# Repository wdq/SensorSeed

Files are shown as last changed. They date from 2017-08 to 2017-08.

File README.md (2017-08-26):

# SensorSeed

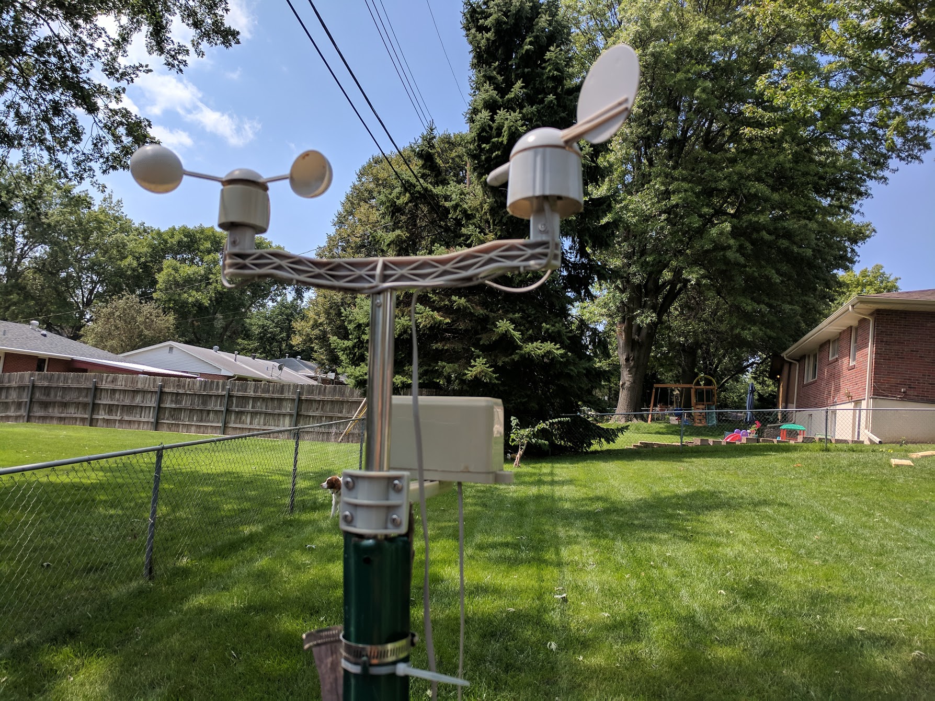
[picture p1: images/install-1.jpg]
Weather station wind and rain sensors


This is everything relating to my weather station project, including C# website code, AVR code for the hardware, PCB layouts, and schematics.

There is an outdoor component to the station that collects temperature, humidity, pressure, wind speed, wind direction, and rain every two and a half minutes, I might bump this up to every minute in the future. Data is pushed over the air using a 100mW 900MHz radio to a Particle Photon inside my house. The Photon is connected to WiFi and uploads the data to the website. 

You can view the data collected from the weather station on [my website](https://sensorseed.quade.co/HomeOutsideWeatherStation/Home), and on the [Weather Underground website](https://www.wunderground.com/personal-weather-station/dashboard?ID=KNELINCO88)

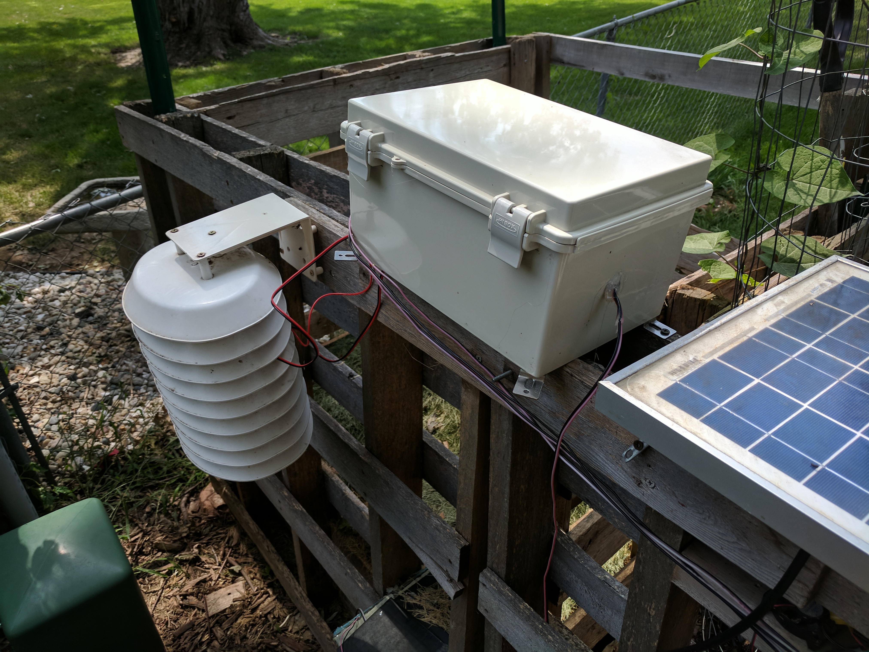
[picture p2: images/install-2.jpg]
Weather station hardware


Parts list: 

| Item | Price | Description |
|---|---|---|
| Outdoor PCB | $15 | The PCB for the outside part of the weather station. I got them made at Elecrow and the price shipped was about $15. |
| Indoor PCB | $15 | The PCB for the indoor part of the weather station. I got them made at Elecrow and the price shipped was about $15. |
| ATmega328p | $2 | Main microcontroller for the outside station. PDIP package. |
| 2x ATtiny44/88 | $4 | I2C slaves that keep track of wind speed and rain outside. PDIP package. |
| 2x Adafruit RFM69HCW | $20 | Radios to handle communication between indoor and outdoor device. I use the 900MHz version with the nine pin breakout. |
| Particle Photon | $20 | The microcontroller for the indoor station. |
| 2x 900MHz antennas | $10 | For the radios. I used right angle SMA ones that Adafruit sells. |
| 2x SMA jacks | $5 | Edge mount SMA jacks for 1.6mm PCBs for the radios. Adafruit sells these. |
| 6x 220 ohm resistors | $0.60 | Through hole package. These are for LEDs, so you can use different sizes based on how bright you want the LEDs to be.  |
| 6x LEDs | $1 | Through hole 5mm LEDs. Any color. |
| 2x 20pF capacitors | $0.20 | Through hole package, ceramic. May be different depending on the crystal oscillator you pick. |
| 6x 0.1uF capacitors | $0.60 | Through hole package, ceramic. For the AVR decoupling. |
| 8MHz crystal | $0.30 | An 8MHz quartz crystal oscillator. You can use other frequencies if you want. |
| 2x 1k ohm resistors | $0.20 | For voltage divider. Through hole. |
| 3x 2k ohm resistors | $0.30 | For voltage divider. Through hole. |
| 10k ohm resistor | $0.10 | For the wind vane. Through hole. |
| 4.7k ohm resistor | $0.10 | Pullup resistor for the radio. Through hole. |
| 2x 10uF capacitors | $0.20 | Bypass capacitors, through hole, one per board, electrolytic. |
| 6x jumpers | $1.00 | Jumpers to turn on/off the LEDs for debugging |
| Pin headers | $1 | Used throughout both boards |
| Pin header sockets | $1 | Used throughout both boards |
| 3x 28 pin DIP sockets | $1 | Used to make the AVR chips removable. |
|  Sparkfun weather meters | $77 | There are lots of distributors. I got mine on Amazon. Has the rain gauge, anemometer, and wind vane. |
| Weatherproof box | $30 | A box to hold the outside station. |
| Solar radiation shield | $40 | Very important for accurate temperature and humidity readings. |
| 35W solar panel | $40 | A panel to charge the battery, bigger is generally better. |
| 12V 18Ah lead acid battery | $40 | To run the outside station. Lead acid charges at lower temperatures than lithium ion. Bigger is generally better. |
| Lead acid solar charge controller | $20 | To charge the battery. |
| Adafruit SHT31-D | $14 | Temperature/humidity sensor. |
| DHT22 | $4 | Temperature/humidity sensor. |
| BMP180 | $4 | Pressure/Temperature/Altitude sensor. |
| Silica Gel packets | $10 | To help keep the outdoor station dry inside the box |
| | | |
| Total: | $378  | 

I recommend buying extras for many of the cheaper electronic parts. That way you can have a replacement board if something goes wrong, and generally buying in bulk is cheaper anyways.

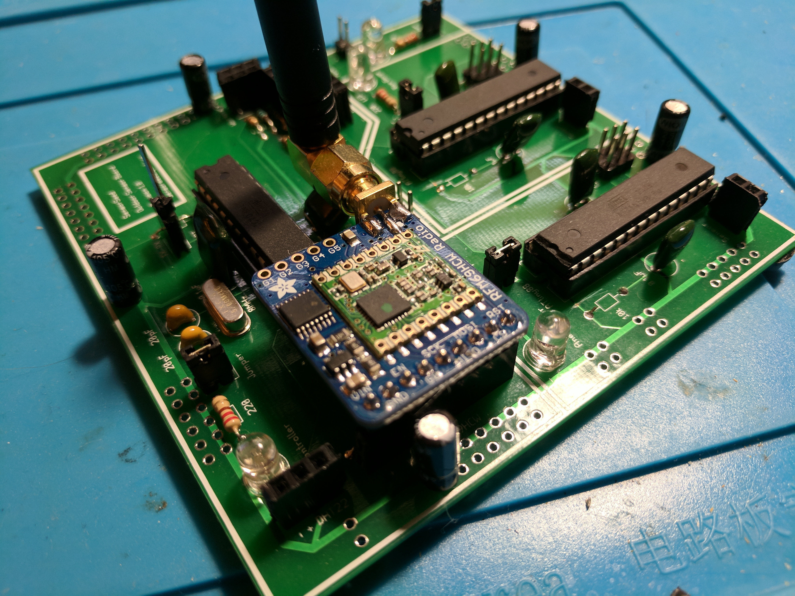
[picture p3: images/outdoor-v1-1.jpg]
Outdoor board

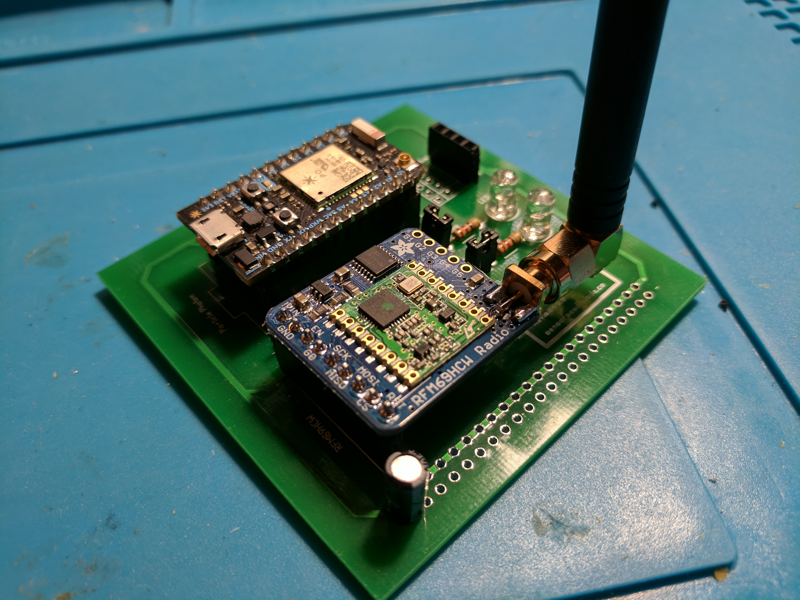
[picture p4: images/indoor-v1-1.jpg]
Indoor board


You can find more images of this station [here](https://github.com/wdq/SensorSeed/tree/master/images).

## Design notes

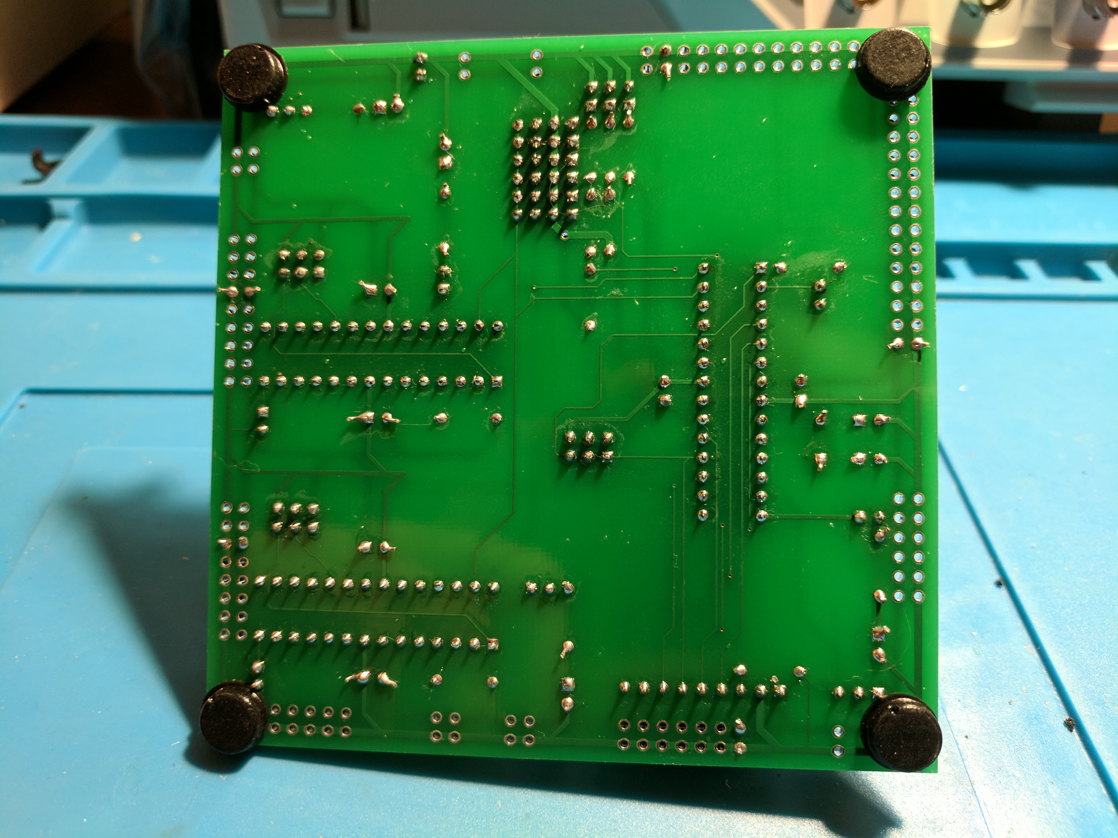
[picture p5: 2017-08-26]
images/outdoor-v1-3.jpg

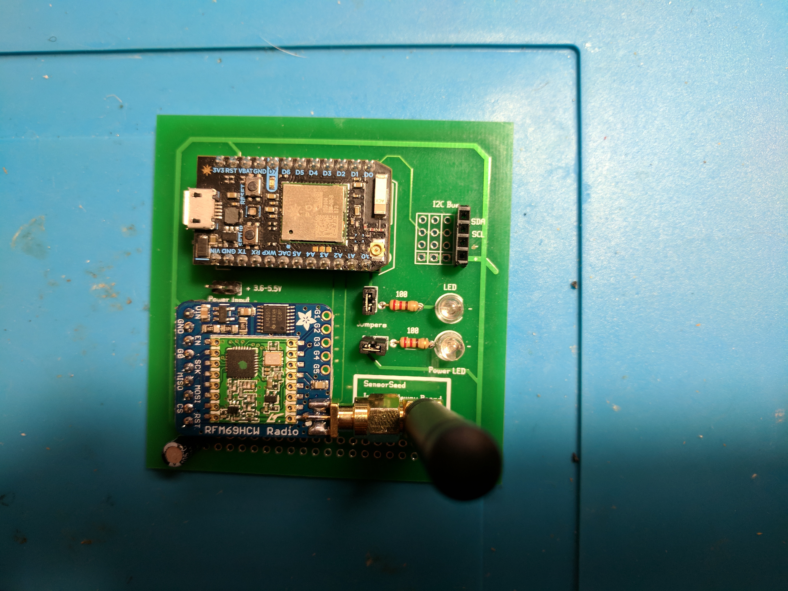
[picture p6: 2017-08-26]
images/indoor-v1-2.jpg

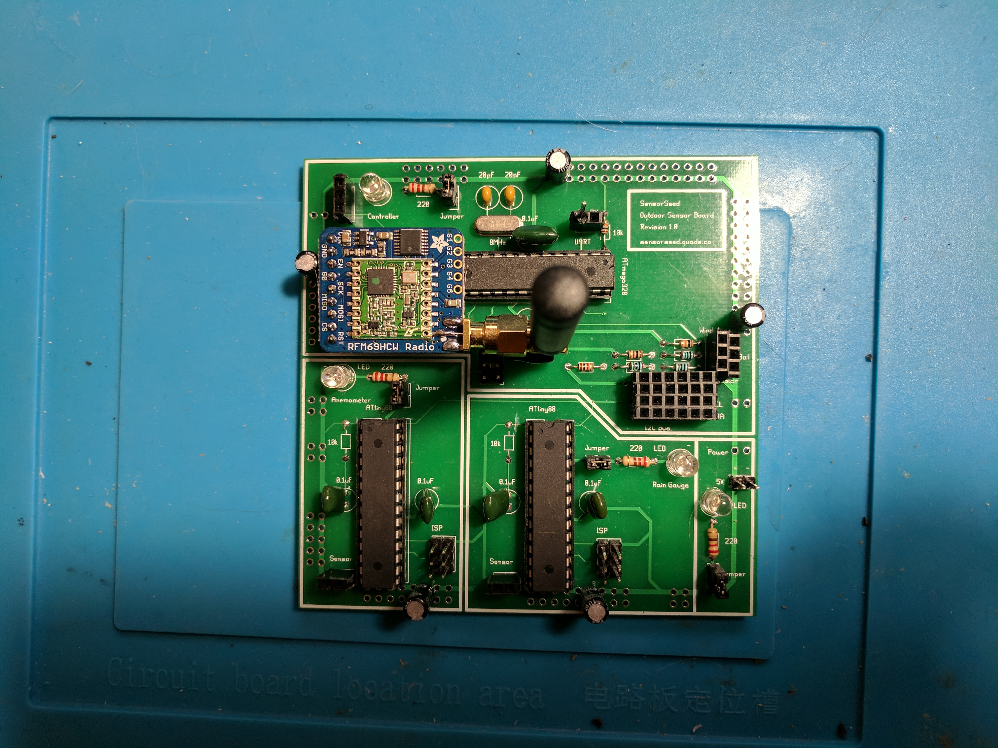
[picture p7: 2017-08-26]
images/outdoor-v1-2.jpg

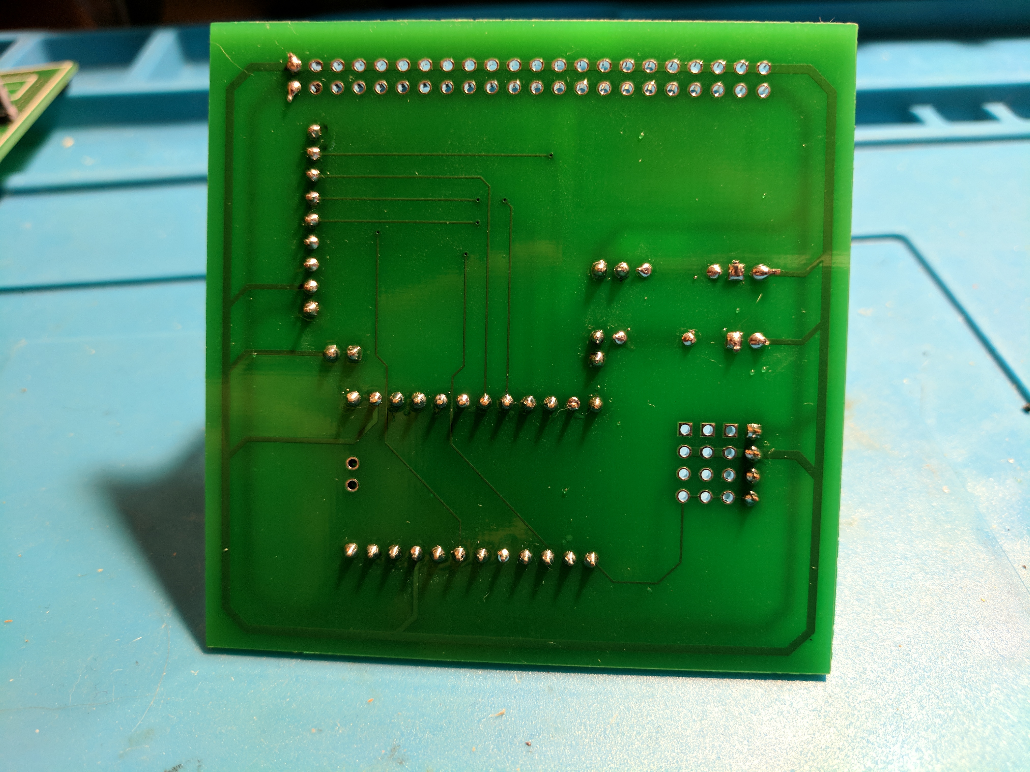
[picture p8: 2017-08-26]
images/indoor-v1-3.jpg

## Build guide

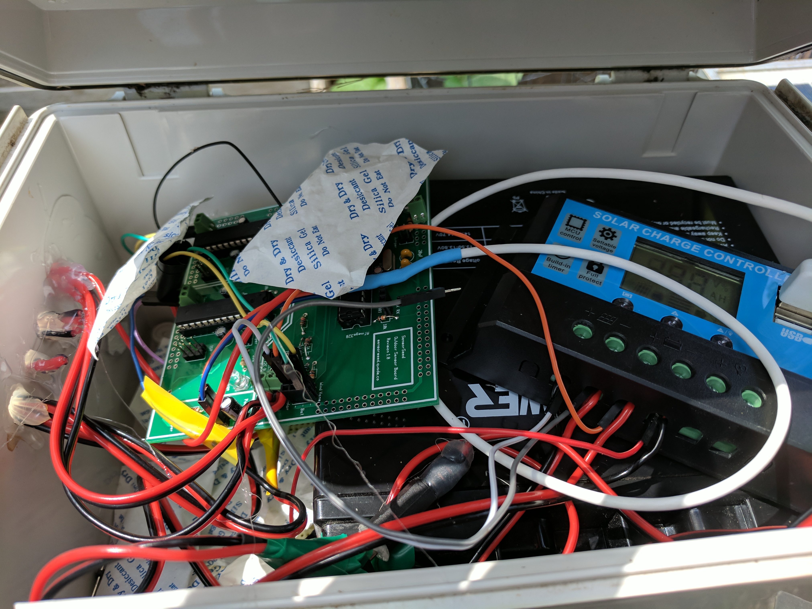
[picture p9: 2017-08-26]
images/install-3.jpg

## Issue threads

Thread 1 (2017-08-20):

Wire.requestFrom() should not be followed by Wire.endTransmission() and no delay is needed after a Wire.requestFrom().

Koepel, 2017-08-20:
In the file "SensorSeed/hardware/avr/outside/outside.ino", the Wire.requestFrom() is followed by a Wire.endTransmission() three times. You can remove those Wire.endTransmission(), since it is should only be used when writing data.

In the function getRain() the Wire.requestFrom() is followed by a `delay(50);`. You can remove that delay, since there is no need to wait after a Wire.requestFrom().

wdq, 2017-08-20:
Thanks for pointing this out, I've updated the code.

Closed 2017-08-20.

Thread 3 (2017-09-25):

Air quality/pollution sensors

wdq, 2017-09-25:
I'd like to add air quality/pollution sensors to the board since they are part of the wunderground API.

Probably won't get around to this until I'm out of school at the end of this year, or in the summer of 2018.

Ideally the sensors would go into the same solar radiation shield that the temperature/humidity/pressure sensors are in, and also use I2C. I'd be designing a new board that goes into there.

Possible fields:

AqNO - [ NO (nitric oxide) ppb ]
AqNO2T - (nitrogen dioxide), true measure ppb
AqNO2 - NO2 computed, NOx-NO ppb
AqNO2Y - NO2 computed, NOy-NO ppb
AqNOX - NOx (nitrogen oxides) - ppb
AqNOY - NOy (total reactive nitrogen) - ppb
AqNO3 -NO3 ion (nitrate, not adjusted for ammonium ion) UG/M3
AqSO4 -SO4 ion (sulfate, not adjusted for ammonium ion) UG/M3
AqSO2 -(sulfur dioxide), conventional ppb
AqSO2T -trace levels ppb
AqCO -CO (carbon monoxide), conventional ppm
AqCOT -CO trace levels ppb
AqEC -EC (elemental carbon) – PM2.5 UG/M3
AqOC -OC (organic carbon, not adjusted for oxygen and hydrogen) – PM2.5 UG/M3
AqBC -BC (black carbon at 880 nm) UG/M3
AqUV-AETH  -UV-AETH (second channel of Aethalometer at 370 nm) UG/M3
AqPM2.5 - PM2.5 mass - UG/M3
AqPM10 - PM10 mass - PM10 mass
AqOZONE - Ozone - ppb

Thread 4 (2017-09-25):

Solar type sensors

wdq, 2017-09-25:
Another part of the wunderground API is solar data.

I tried to do this in the past, but the weather got to the sensors. They need to be in a good glass enclosure where they can see the sky.

Ideally they would use I2C.

I probably won't get around to this until I am off of school at the end of this year, or the summer of 2018.

Data fields:

solarradiation - [W/m^2]
UV - [index]

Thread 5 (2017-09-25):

Add soil type sensors

wdq, 2017-09-25:
Another type of data that the wunderground API supports are for soil sensors.

This is something I have been working on at work, so I might incorporate part of that design into this. That would be a capacitive moisture sensor that has an I2C interface.

Do a single depth at a minimum, but consider doing multiple depths.

I probably won't be getting around to this until the summer of 2018 when I am off of school.

Data fields:

soiltempf - [F soil temperature]
 * for sensors 2,3,4 use soiltemp2f, soiltemp3f, and soiltemp4f
soilmoisture - [%]
* for sensors 2,3,4 use soilmoisture2, soilmoisture3, and soilmoisture4

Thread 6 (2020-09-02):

PCB fabrication

zjobra, 2020-09-02:
Hi!
I've uploaded SensorSeed boards to pcbhubs for easy manufacturing order
https://pcbhubs.com/newpcb/15990737105f4fedae3fdff
https://pcbhubs.com/newpcb/15990737865f4fedfa4907c

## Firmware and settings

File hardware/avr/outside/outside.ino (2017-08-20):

// outside
// This code is for an ATmega328p I2C master to collect data from a bunch of sensors.

#include <Wire.h>
#include <RFM69.h>
#include <SPI.h>
#include <Adafruit_SHT31.h>
#include <Adafruit_Sensor.h>
#include <Adafruit_BMP085_U.h>
#include <DHT.h>
#include <DHT_U.h>
#include <stdlib.h>

#define NETWORKID                               81
#define NODEID                                  2
#define RECEIVER                                1
#define FREQUENCY                               RF69_915MHZ
#define ENCRYPTKEY                              "wquadeEncryptKey"
#define IS_RFM69HCW                             true
#define TRANSMIT_INTERVAL                       90000 // in milliseconds, this is set to 1.5 minutes
#define TIME_BETWEEN_PACKETS                    15000 // 15 seconds

// I2C slaves
#define ANEMOMETER_I2C_ADDRESS                  0x06
#define RAINGAUGE_I2C_ADDRESS                   0x07
#define WIND_FACTOR                             2.4
// IO pins
#define LED_PIN                                 14
#define VANE_PIN                                A1
#define VANE_EN_PIN                             A0
#define SOLAR_PIN                               A3
#define BATTERY_PIN                             A2
#define SERIAL_BAUD                             9600                             
// DHT22
#define DHTPIN                                  7
#define DHTTYPE                                 DHT22
// RFM69HCW
#define RFM69_CS                                4
#define RFM69_IRQ                               3
#define RFM69_IRQN                              1
#define RFM69_RST                               2


int16_t packetnum = 0;
unsigned long previousTransmitMillis = millis();
unsigned long previousPacketSentMillis = millis();
unsigned long previousWindSpeedRetrieveMillis = millis();
bool transmitting = false;

int state = 0;
char radiopacket0[61];
char radiopacket1[61];
char radiopacket2[61];
char radiopacket3[61];
char radiopacket4[61];

RFM69 radio = RFM69(RFM69_CS, RFM69_IRQ, IS_RFM69HCW, RFM69_IRQN);
Adafruit_SHT31 sht31 = Adafruit_SHT31();
Adafruit_BMP085_Unified bmp180 = Adafruit_BMP085_Unified(10085);
DHT_Unified dht(DHTPIN, DHTTYPE);

bool sht31Connected = false;
bool bmp180Connected = false;

void enableRadio() {
  pinMode(RFM69_RST, OUTPUT);
  digitalWrite(RFM69_RST, HIGH);
  delay(100);
  digitalWrite(RFM69_RST, LOW);
  delay(100);
  radio.initialize(FREQUENCY,NODEID,NETWORKID);
  if (IS_RFM69HCW) {
    radio.setHighPower();
  }
  radio.setPowerLevel(31);
  radio.encrypt(ENCRYPTKEY);
  Serial.println(F("Radio enabled"));
}

void setupSensors() {
  // Reset rain gauge and anemometer.
  Serial.print("Resetting rain gauge and anemometer...");
  Wire.beginTransmission(RAINGAUGE_I2C_ADDRESS);
  Wire.write(1);
  Wire.endTransmission();
  Wire.beginTransmission(ANEMOMETER_I2C_ADDRESS);
  Wire.write(1);
  Wire.endTransmission();
  previousWindSpeedRetrieveMillis = millis();
  Serial.println(F("SHT31 begin "));
  sht31Connected = sht31.begin(0x44);
  if(!sht31Connected) {
    Serial.println(F("FAILED"));
  }
  Serial.println(F("BMP180 begin "));
  bmp180Connected = bmp180.begin();
  if(!bmp180Connected) {
    Serial.println(F("FAILED"));
  }
  dht.begin(); // library doesn't return a status on begin
  pinMode(VANE_PIN, INPUT);
  pinMode(VANE_EN_PIN, OUTPUT);
  digitalWrite(VANE_EN_PIN, LOW);
  pinMode(BATTERY_PIN, INPUT);
  pinMode(SOLAR_PIN, INPUT);
  Serial.println(F("Sensors setup"));
}

void setup() {
  Serial.begin(SERIAL_BAUD);
  Serial.println(F("Starting station..."));
  enableRadio();
  setupSensors();

  Serial.println(F("Sending test packet"));
  String packet0 = String();
  String packet0Data = String("Hello world");
  packet0 += String("0:");
  packet0 += packet0Data;
  memset(radiopacket0, 0, sizeof(radiopacket0));
  packet0.toCharArray(radiopacket0, 61);
  Serial.print(F("Sending: ")); Serial.println(radiopacket0);
  radio.send(RECEIVER, radiopacket0, strlen(radiopacket0)); //target node Id, message as string or byte array, message length
  Serial.println(F("OK"));
  radio.receiveDone(); //put radio in RX mode
  Serial.flush(); //make sure all serial data is clocked out before sleeping the MCU  
  Serial.println(F("Finished setup"));
}

bool waitingBetweenPackets = false;
void loop() {
  unsigned long currentMillis = millis();
  if((currentMillis - previousTransmitMillis > TRANSMIT_INTERVAL) && !transmitting) {
    state = 1; // create packets
    Serial.println(F("Creating packets"));
  } else if((currentMillis - previousPacketSentMillis > TIME_BETWEEN_PACKETS) && transmitting) {
    state++;
    waitingBetweenPackets = false;
    Serial.println(F("Incrementing state"));    
  }
  
  if(state == 1) { // create packets
      Serial.println(F("Creating packets"));
      String packet1 = String();
      String packet2 = String();
      String packet3 = String();
      String packet4 = String();

      String temperatureSHT31 = String();
      String humiditySHT32 = String();
      if(sht31Connected) {
        temperatureSHT31 = String(getTemperatureSHT31());
        humiditySHT32 = String(getHumiditySHT31());
      } else {
        temperatureSHT31 = String("0.00");
        humiditySHT32 = String("0.00");
      }
      String pressureBMP180 = String();
      String altitudeBMP180 = String();
      String temperatureBMP180 = String();
      if(bmp180Connected) {
        pressureBMP180 = String(getPressureBMP180());
        altitudeBMP180 = String(getAltitudeBMP180());
        temperatureBMP180 = String(getTemperatureBMP180());
      } else {
        pressureBMP180 = String("0.00");
        altitudeBMP180 = String("0.00");
        temperatureBMP180 = String("0.00");        
      }
      
      String windSpeed = String(getWind());
      String gustSpeed = String(getGust());
      
      String rain = String(getRain());
      String battery = String(getBattery());
      Serial.print(F("Battery string: "));
      Serial.print(battery);
      Serial.print(F(", battery float: "));
      Serial.println(getBattery());
      String solar = String(getSolar());
      
      String windDirection = String(getDirection());
      
      String temperatureDHT22 = String(getTemperatureDHT22());
      String humidityDHT22 = String(getHumidityDHT22());

      packet1 += String("1:");
      packet1 += temperatureSHT31;
      packet1 += String(",");
      packet1 += humiditySHT32;
      packet1 += String(",");  
      packet1 += pressureBMP180;
      packet1 += String(",");
      packet1 += altitudeBMP180;
    
      packet2 += String("2:");  
      packet2 += windSpeed;
      packet2 += String(",");
      packet2 += gustSpeed;
    
      packet3 += String("3:");
      packet3 += rain;
      packet3 += String(",");
      packet3 += battery;
      packet3 += String(",");
      packet3 += solar;
    
      packet4 += String("4:");
      packet4 += windDirection;
      packet4 += String(",");
      packet4 += temperatureBMP180;
      packet4 += String(",");
      packet4 += temperatureDHT22;
      packet4 += String(",");
      packet4 += humidityDHT22;

      memset(radiopacket1, 0, sizeof(radiopacket1));
      memset(radiopacket2, 0, sizeof(radiopacket2));
      memset(radiopacket3, 0, sizeof(radiopacket3));
      memset(radiopacket4, 0, sizeof(radiopacket4));
      packet1.toCharArray(radiopacket1, 61);
      packet2.toCharArray(radiopacket2, 61);
      packet3.toCharArray(radiopacket3, 61);
      packet4.toCharArray(radiopacket4, 61);

      Serial.println(F("All packets are ready"));
      Serial.println(radiopacket1);
      Serial.println(radiopacket2);
      Serial.println(radiopacket3);
      Serial.println(radiopacket4);
      state = 2; // send packet 1
      transmitting = true;
      waitingBetweenPackets = false;         
  }

  if(state == 2 && !waitingBetweenPackets) { // send packet 1
      Serial.print(F("Sending ")); Serial.println(radiopacket1);
      radio.send(RECEIVER, radiopacket1, strlen(radiopacket1)); //target node Id, message as string or byte array, message length
      Serial.println(F("OK"));
      radio.receiveDone(); //put radio in RX mode
      Serial.flush(); //make sure all serial data is clocked out before sleeping the MCU
      previousPacketSentMillis = millis();
      waitingBetweenPackets = true;
  }
  if(state == 3 && !waitingBetweenPackets) { // send packet 2
      Serial.print(F("Sending ")); Serial.println(radiopacket2);
      radio.send(RECEIVER, radiopacket2, strlen(radiopacket2)); //target node Id, message as string or byte array, message length
      Serial.println(F("OK"));
      radio.receiveDone(); //put radio in RX mode
      Serial.flush(); //make sure all serial data is clocked out before sleeping the MCU
      previousPacketSentMillis = millis();
      waitingBetweenPackets = true;       
  }
  if(state == 4 && !waitingBetweenPackets) { // send packet 3
      Serial.print(F("Sending ")); Serial.println(radiopacket3);
      radio.send(RECEIVER, radiopacket3, strlen(radiopacket3)); //target node Id, message as string or byte array, message length
      Serial.println(F("OK"));
      radio.receiveDone(); //put radio in RX mode
      Serial.flush(); //make sure all serial data is clocked out before sleeping the MCU
      previousPacketSentMillis = millis();  
      waitingBetweenPackets = true;   
  }
  if(state == 5 && !waitingBetweenPackets) { // send packet 4   
      Serial.print(F("Sending ")); Serial.println(radiopacket4);
      radio.send(RECEIVER, radiopacket4, strlen(radiopacket4)); //target node Id, message as string or byte array, message length
      Serial.println(F("OK"));
      radio.receiveDone(); //put radio in RX mode
      Serial.flush(); //make sure all serial data is clocked out before sleeping the MCU
      previousPacketSentMillis = millis();  
      previousTransmitMillis = currentMillis;
      transmitting = false;
      state = 0;
      waitingBetweenPackets = false;
  }
}

float getTemperatureSHT31() {
  float temperature = sht31.readTemperature();
  return temperature;
}

float getHumiditySHT31() {
  float humidity = sht31.readHumidity();
  return humidity;
}

float getPressureBMP180() {
  sensors_event_t event;
  bmp180.getEvent(&event);
  return event.pressure;
}

float getAltitudeBMP180() {
  sensors_event_t event;
  bmp180.getEvent(&event);
  float seaLevelPressure = SENSORS_PRESSURE_SEALEVELHPA;
  return bmp180.pressureToAltitude(seaLevelPressure, event.pressure);
}

double getWind() {
  Wire.beginTransmission(ANEMOMETER_I2C_ADDRESS);
  Wire.write(2);
  Wire.endTransmission();
  unsigned long previousWindSpeedRetrieveMillisTemp = previousWindSpeedRetrieveMillis;
  previousWindSpeedRetrieveMillis = millis();
  delay(50);
  Wire.requestFrom(ANEMOMETER_I2C_ADDRESS, 4);
  byte dataBuffer[4];
  int i = 0;
  while(Wire.available()) {
    dataBuffer[i] = Wire.read();
    i++;    
  }
  union dataUnionTag {byte dataBytes[4]; unsigned long dataLong;} dataUnion;
  dataUnion.dataBytes[0] = dataBuffer[0];
  dataUnion.dataBytes[1] = dataBuffer[1];
  dataUnion.dataBytes[2] = dataBuffer[2];
  dataUnion.dataBytes[3] = dataBuffer[3];
  unsigned long anemometerClicks = dataUnion.dataLong;
  double wind = (WIND_FACTOR*anemometerClicks)/((previousWindSpeedRetrieveMillis-previousWindSpeedRetrieveMillisTemp) / 1000);
  
  return wind;
}

double getGust() {
  Wire.beginTransmission(ANEMOMETER_I2C_ADDRESS);  
  Wire.write(3);
  Wire.endTransmission();
  delay(50);
  Wire.requestFrom(ANEMOMETER_I2C_ADDRESS, 4);
  byte dataBuffer[4];
  int i = 0;
  while(Wire.available()) {
    dataBuffer[i] = Wire.read();
    i++;
  }
  union dataUnionTag {byte dataBytes[4]; unsigned long dataLong;} dataUnion;
  dataUnion.dataBytes[0] = dataBuffer[0];
  dataUnion.dataBytes[1] = dataBuffer[1];
  dataUnion.dataBytes[2] = dataBuffer[2];
  dataUnion.dataBytes[3] = dataBuffer[3];
  unsigned long anemometerMin = dataUnion.dataLong;
  double gust = (1/(anemometerMin/1000000.0)) * WIND_FACTOR;

  // Reset the anemometer
  Wire.beginTransmission(ANEMOMETER_I2C_ADDRESS);
  Wire.write(1);
  Wire.endTransmission();
  previousWindSpeedRetrieveMillis = millis();  
  
  return gust;  
}

float getRain() {
  Wire.beginTransmission(RAINGAUGE_I2C_ADDRESS);
  Wire.write(2);
  Wire.endTransmission();
  delay(50);
  Wire.requestFrom(RAINGAUGE_I2C_ADDRESS, 4);
  byte dataBuffer[4];
  int i = 0;
  while(Wire.available()) {
    dataBuffer[i] = Wire.read();    i++;
  }
  union dataUnionTag {byte dataBytes[4]; float dataFloat;} dataUnion;
  dataUnion.dataBytes[0] = dataBuffer[0];
  dataUnion.dataBytes[1] = dataBuffer[1];
  dataUnion.dataBytes[2] = dataBuffer[2];
  dataUnion.dataBytes[3] = dataBuffer[3];
  float rain = dataUnion.dataFloat;
  
  return rain;
}

float getBattery() {
  float measuredvbat = analogRead(BATTERY_PIN);
  return measuredvbat;
}

float getSolar() {
  float measuredvsolar = analogRead(SOLAR_PIN);
  return measuredvsolar;
}

int averageAnalogRead(int pinToRead)
{
  byte numberOfReadings = 8;
  unsigned int runningValue = 0;

  for (int x = 0 ; x < numberOfReadings ; x++)
    runningValue += analogRead(pinToRead);
  runningValue /= numberOfReadings;

  return (runningValue);
}

unsigned int getDirection() {
  digitalWrite(VANE_EN_PIN, HIGH);
  unsigned int adc;
  adc = averageAnalogRead(VANE_PIN);
  digitalWrite(VANE_EN_PIN, LOW);
  
  return adc;
}


float getTemperatureBMP180() {
  sensors_event_t event;
  bmp180.getEvent(&event);
  float temperature;
  bmp180.getTemperature(&temperature);
  return temperature;
}

float getTemperatureDHT22() {
  sensors_event_t event;
  dht.temperature().getEvent(&event);
  return event.temperature;
}

float getHumidityDHT22() {
  sensors_event_t event;
  dht.humidity().getEvent(&event);
  return event.relative_humidity;
}

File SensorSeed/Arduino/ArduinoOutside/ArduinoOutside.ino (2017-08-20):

#include <Wire.h>
#include <RFM69.h>
#include <SPI.h>
#include <Adafruit_SHT31.h>
#include <Adafruit_Sensor.h>
#include <Adafruit_BMP085_U.h>
#include <DHT.h>
#include <DHT_U.h>
#include <stdlib.h>

// Settings for the Adafruit RFM69HCW radio
#define NETWORKID     81
#define NODEID        2
#define RECEIVER      1
#define FREQUENCY     RF69_915MHZ
#define ENCRYPTKEY    "wquadeEncryptKey"
#define IS_RFM69HCW   true
int16_t packetnum = 0;
#define TRANSMIT_INTERVAL 90000 // in milliseconds, this is set to 1.5 minutes
#define TIME_BETWEEN_PACKETS 15000
unsigned long previousTransmitMillis = millis();
unsigned long previousPacketSentMillis = millis();
bool transmitting = false;

// Settings for the DHT22
#define DHTPIN            4
#define DHTTYPE           DHT22

// Pins for the Adafruit RFM69HCW radio
#define RFM69_CS      10
#define RFM69_IRQ     2
#define RFM69_IRQN    0  // IRQ 0
#define RFM69_RST     9
#define LED           13

// Other pins

#define VANE_PIN A1
#define SOLAR_PIN A2
#define BATTERY_PIN A3

// Anemometer settings
#define ANEMOMETER_PIN 3
#define ANEMOMETER_INT 1
#define WIND_FACTOR 2.4
#define TEST_PAUSE 60000
volatile unsigned long anem_count=0;
volatile unsigned long anem_last=0;
volatile unsigned long anem_min=0xffffffff;
unsigned long previousWindSpeedRetrieveMillis = millis();

// Rain settings
#define RAIN_GAUGE_PIN 5
#define RAIN_FACTOR 0.2794 // millimeters
volatile unsigned long rain_count=0;
volatile unsigned long rain_last=0;

#define SERIAL_BAUD   9600
int state = 0;
char radiopacket1[61];
char radiopacket2[61];
char radiopacket3[61];
char radiopacket4[61];


// Setup some libraries for devices
RFM69 radio = RFM69(RFM69_CS, RFM69_IRQ, IS_RFM69HCW, RFM69_IRQN);
Adafruit_SHT31 sht31 = Adafruit_SHT31();
Adafruit_BMP085_Unified bmp180 = Adafruit_BMP085_Unified(10085);
DHT_Unified dht(DHTPIN, DHTTYPE);

void setupRadio() {
  // Hard Reset the RFM module
  pinMode(RFM69_RST, OUTPUT);
  digitalWrite(RFM69_RST, HIGH);
  delay(100);
  digitalWrite(RFM69_RST, LOW);
  delay(100);  
  // Initialize radio
  radio.initialize(FREQUENCY,NODEID,NETWORKID);
  if (IS_RFM69HCW) {
    radio.setHighPower();    // Only for RFM69HCW & HW!
  }
  radio.setPowerLevel(31); // power output ranges from 0 (5dBm) to 31 (20dBm)
  
  radio.encrypt(ENCRYPTKEY);
  
  pinMode(LED, OUTPUT);
  Serial.print("\nTransmitting at ");
  Serial.print(FREQUENCY==RF69_433MHZ ? 433 : FREQUENCY==RF69_868MHZ ? 868 : 915);
  Serial.println(" MHz");  
}


void initializeSensors() {
  sht31.begin(0x44);
  bmp180.begin();
  dht.begin();
  pinMode(VANE_PIN,INPUT);
  pinMode(ANEMOMETER_PIN,INPUT);  
  pinMode(RAIN_GAUGE_PIN,INPUT);
  attachInterrupt(ANEMOMETER_INT,anemometerClick,FALLING);
  pinMode(BATTERY_PIN, INPUT);
  pinMode(SOLAR_PIN, INPUT);    
}

void setup() {
  Serial.begin(SERIAL_BAUD);
  Serial.println("Starting Arduino outside weather station...");
  setupRadio();
  initializeSensors();
  Serial.println("Setup complete");
}

void loop() {
  unsigned long currentMillis = millis();
  if((currentMillis - previousTransmitMillis > TRANSMIT_INTERVAL) && !transmitting) {
    state = 1; // create packets 
  } else if((currentMillis - previousPacketSentMillis > TIME_BETWEEN_PACKETS) && transmitting) {
    state++;    
  }

  if(digitalRead(RAIN_GAUGE_PIN)) {
    if((micros() - rain_last) > 500) {
      rain_count++;        
    }
    rain_last = micros();
  }

  
  if(state == 1) { // create packets
      String packet1 = String();
      String packet2 = String();
      String packet3 = String();
      String packet4 = String();
      
      String temperatureSHT31 = String(getTemperatureSHT31());
      String humiditySHT32 = String(getHumiditySHT31());
      String pressureBMP180 = String(getPressureBMP180());
      String altitudeBMP180 = String(getAltitudeBMP180());
      
      String windSpeed = String(getUnitWind());
      String gustSpeed = String(getGust());
      
      String rain = String(getUnitRain());
      String battery = String(getBattery());
      String solar = String(getSolar());
      
      String windDirection = String(getDirection());
      String temperatureBMP180 = String(getTemperatureBMP180());
      String temperatureDHT22 = String(getTemperatureDHT22());
      String humidityDHT22 = String(getHumidityDHT22());

      packet1 += String("1:");
      packet1 += temperatureSHT31;
      packet1 += String(",");
      packet1 += humiditySHT32;
      packet1 += String(",");  
      packet1 += pressureBMP180;
      packet1 += String(",");
      packet1 += altitudeBMP180;
    
      packet2 += String("2:");  
      packet2 += windSpeed;
      packet2 += String(",");
      packet2 += gustSpeed;
    
      packet3 += String("3:");
      packet3 += rain;
      packet3 += String(",");
      packet3 += battery;
      packet3 += String(",");
      packet3 += solar;
    
      packet4 += String("4:");
      packet4 += windDirection;
      packet4 += String(",");
      packet4 += temperatureBMP180;
      packet4 += String(",");
      packet4 += temperatureDHT22;
      packet4 += String(",");
      packet4 += humidityDHT22;

      memset(radiopacket1, 0, sizeof(radiopacket1));
      memset(radiopacket2, 0, sizeof(radiopacket2));
      memset(radiopacket3, 0, sizeof(radiopacket3));
      memset(radiopacket4, 0, sizeof(radiopacket4));
      packet1.toCharArray(radiopacket1, 61);
      packet2.toCharArray(radiopacket2, 61);
      packet3.toCharArray(radiopacket3, 61);
      packet4.toCharArray(radiopacket4, 61);
      state = 2; // send packet 1
      transmitting = true;         
  }
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

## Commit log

2016-05-19 Fix dew point and heat index calculations. Round variables to two decimal places for display.
2016-05-21 Switch temperature chart to flot. I've used flot in the past. When compared with d3 it's easier to use, but much slower.
2016-05-22 Temperature graph from json.
2016-05-22 Add DewPoint and FeelsLikeTemperature to the temperature graph, add line smoothing.
2016-05-22 Add code to add new sensor data to database. Some style adjustments to the 10 day weather history graph and table. Set up navigation title and links. Create sensorseed home page. Deploy project to II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
2016-05-24 Add battery and solar chart.
2016-05-24 Add humidity/pressure chart.
2016-05-24 Fix colors for humidty/pressure chart.
2016-05-26 Add sunrise and sunset times to home page. Reduce height of power chart. Start on converting a C moon library to C# (for moon percent visible and moon phase).
2016-05-28 Fix typo in indoor sensor retreival code.
2016-05-28 Update lat and lon with actual GPS coordinates (the altitude from the sensor was correct).
2016-05-30 Switch wind graph to a scatter plot.
2016-06-07 Added some more sensors to the readme.
2016-06-09 Add in VEML6070 and lux sensor to the database update code.
2016-06-09 Add the two new light sensors to the home page.
2016-06-09 Add in Arduino code.
2016-06-10 Fix UV Index label, fix wind chart Y axis range.
2016-06-13 Split battery and solar chart into two axes.
2016-06-19 Add DHT22 sensor to the project, change the IP address of the station.
2016-06-19 Add DHT22 code to the Arduino code.
2016-07-03 Arduino code changes.
2016-07-03 Data service that works with raspberry pi.
2016-07-03 Arduino slave code that works with raspberry pi.
2016-07-03 Raspberry Pi code.
2016-07-06 Update Feather code to get analog values over I2C.
2016-07-07 Untested arduino radio transmitter code.
2016-07-07 Untested Arduino receiver code.
2016-07-09 Radio communication works now, haven't tested the indoor I2C slave interface with a Pi yet.
2016-07-09 Split slave data into four packets, adjust data Windows service, handle missing values on the website.
    [ArduinoIndoorReceiverI2cSlave.ino]
2016-07-09 New Arduino code.
2016-07-10 Arduino code to store the new sensor data into a MySQL database.
2016-07-12 Split the temperature chart up into multiple series so that lines aren't drawn in between points that are more than 30 minutes apart.
2016-07-12 Split up humidity/pressure chart series.
2016-07-12 Split up series of power chart.
2016-07-15 Update readme with the current hardware.
2016-07-20 Connect solar and battery voltages directly to ADC, no more voltage divider.
2016-07-21 Update power chart range.
2016-07-28 Print Arduino data over serial, speed up chart loading by only showing some of the data points, update data retrieval program.
2016-07-31 Average the three temperature readings, and the two humidity readings for the charts. Add back in feels like to the temperature chart.
2016-08-06 Adjust power chart to use dynamic range, switch home page to show last updated datetime instead of seconds ago.
2017-08-20 Add board layout files, schematics, and gerber files.
    [attiny48.sch, sensorseedgateway.sch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]
2017-08-20 Fix issue #1: Wire.requestFrom() should not be followed by Wire.endTransmission() and no delay is needed after a Wire.requestFrom()
    [outside.ino]
2017-08-25 Offset direction of wind vane sensor to match physical sensor orientation.
2017-08-25 Switch to decimals for wunderground API conversion math for better precision. Offset the pressure so it matches reality (not sure why wunderground changes what is uploaded).
2017-08-28 Avoid using the DHT22 humidity value when possible on wunderground upload, since the sensor seems to be stuck at >99%.
2017-08-29 Get rid of the DHT22 values on the temperature too, since the sensor is sometimes wrong.
2017-08-30 Switch configs to use localhost instead of an external sql server.
